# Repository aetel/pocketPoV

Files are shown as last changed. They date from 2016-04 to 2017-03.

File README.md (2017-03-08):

# pocketPoV
This little device can serve as a Persistence of View (PoV) display. Just make it swing in the air and it will display a message.

it works! pocketPoV

To program the ATtiny85 you may follow this guide:
http://highlowtech.org/?p=1706

---


pocketPoV and its surrounding materials are published under [CC BY-SA 4.0](https://creativecommons.org/licenses/by-sa/4.0/)

pocketPoV was designed by [RS](https://github.com/rsre "RS") & CBS for Telecom Electronics Association [AETEL](http://aetel.io), based at the Campus Sur of [Universidad Politécnica de Madrid](http://upm.es).

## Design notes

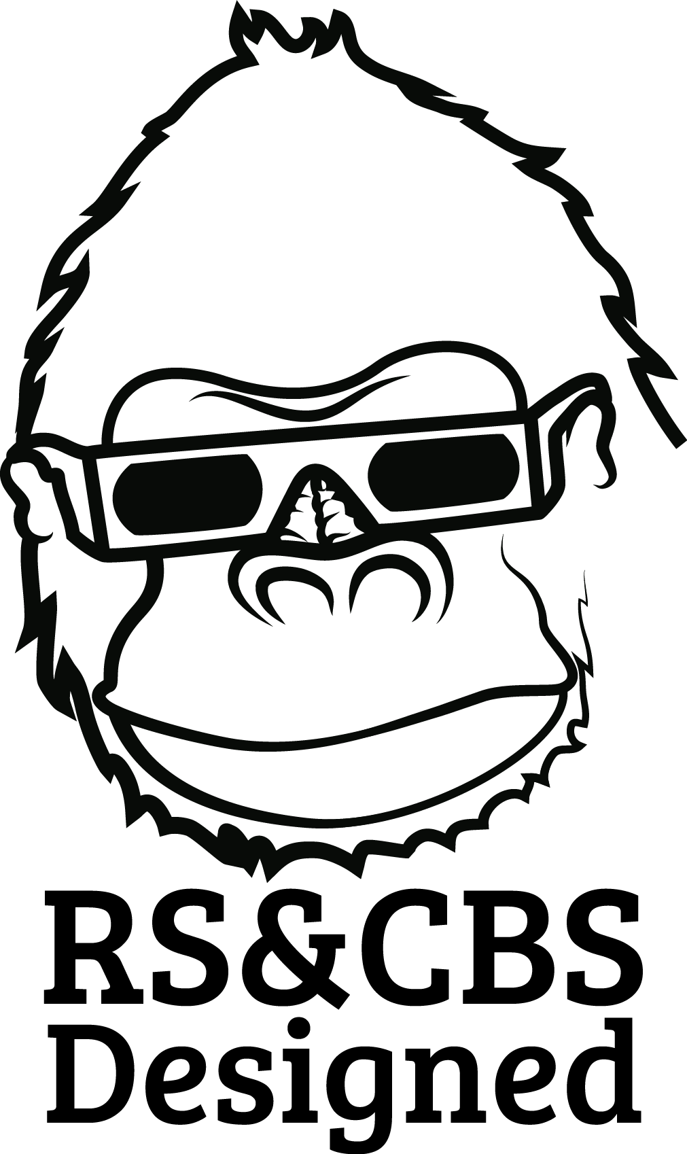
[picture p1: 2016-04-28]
images/RS&CBS.png

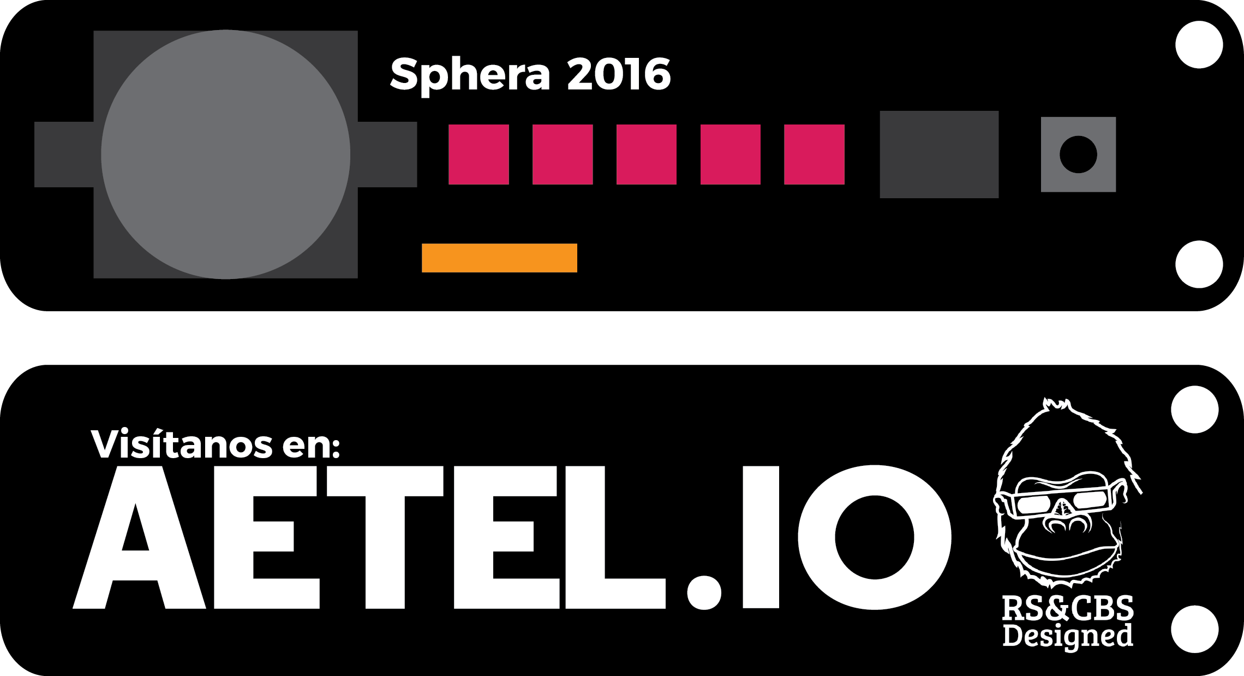
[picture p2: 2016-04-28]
images/pocketPoV.png

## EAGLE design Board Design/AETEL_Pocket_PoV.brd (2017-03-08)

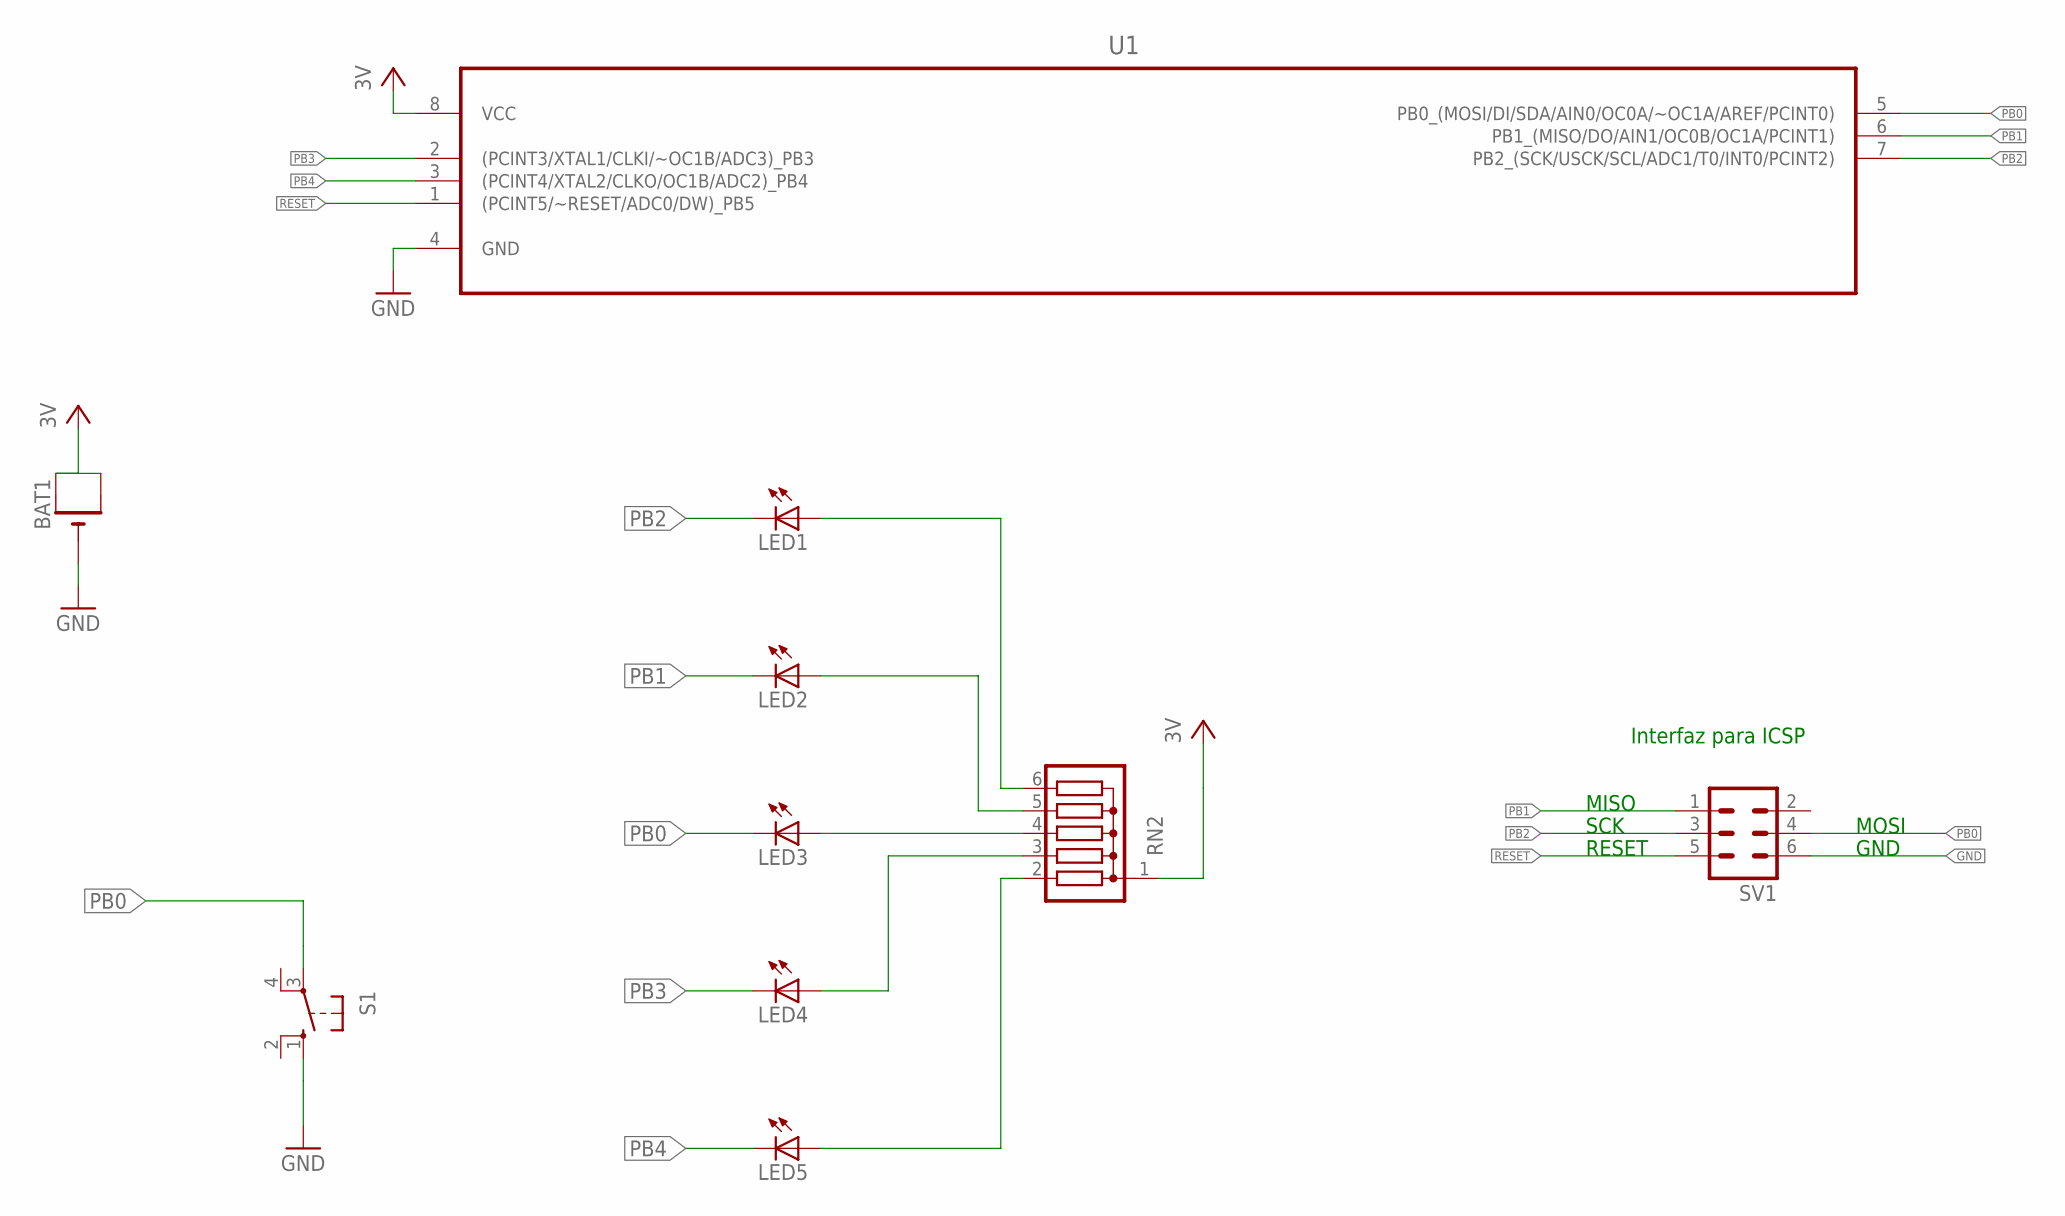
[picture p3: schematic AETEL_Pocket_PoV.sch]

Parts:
BAT1: CR2032THM; CR2032-THRU
LED1, LED2, LED3, LED4, LED5: LEDSQUARE_LED5MM; SQUARE_LED5MM
RN2: G05R; SIL6
S1: 10-XX; B3F-10XX
SV1: MA03-2
U1: ATTINY85-20PU; DIP254P762X533-8

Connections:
GND: BAT1.-, S1.1 (S), SV1.6, U1.4 (GND)
unnamed: LED3.A, RN2.4
unnamed: LED1.A, RN2.6
unnamed: LED2.A, RN2.5
unnamed: LED5.A, RN2.2
unnamed: LED4.A, RN2.3
PB0: LED3.K (C), S1.3, SV1.4, U1.5 (PB0_(MOSI/DI/SDA/AIN0/OC0A/~OC1A/AREF/P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)
PB1: LED2.K (C), SV1.1, U1.6 (PB1_(MISO/DO/AIN1/OC0B/OC1A/PCINT1))
PB2: LED1.K (C), SV1.3, U1.7 (PB2_(SCK/USCK/SCL/ADC1/T0/INT0/PCINT2))
PB3: LED4.K (C), U1.2 ((PCINT3/XTAL1/CLKI/~OC1B/ADC3)_PB3)
PB4: LED5.K (C), U1.3 ((PCINT4/XTAL2/CLKO/OC1B/ADC2)_PB4)
RESET: SV1.5, U1.1 ((PCINT5/~RESET/ADC0/DW)_PB5)
VCC: BAT1.+1 (+), BAT1.+2 (+1), RN2.1, U1.8 (VCC)

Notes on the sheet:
MOSI
MISO
SCK
RESET
GND
Interfaz para ICSP

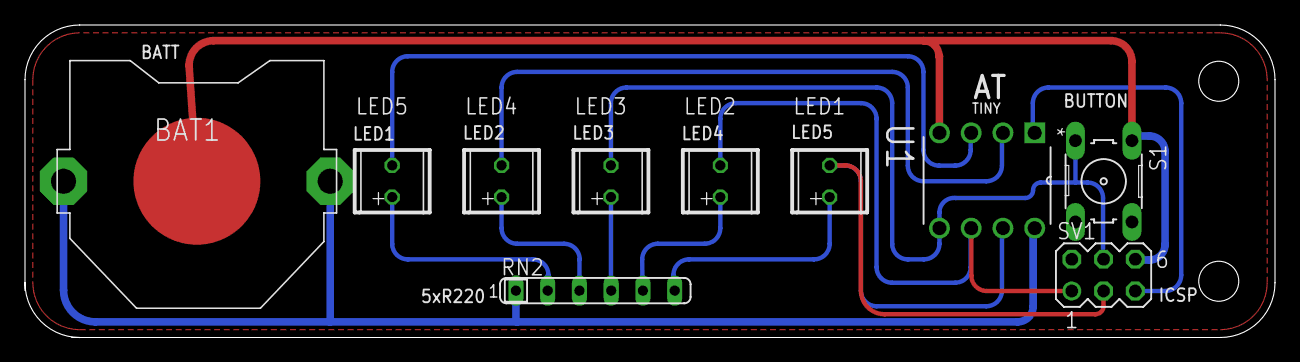
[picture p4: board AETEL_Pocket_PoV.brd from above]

Board: 2 copper layers, 100.0 x 25.0 mm, 10 parts (0 on the bottom side), 13 nets.

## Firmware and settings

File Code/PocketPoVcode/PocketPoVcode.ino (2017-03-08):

/*
 * Pocket PoV code example
 *
 * by RS
 * April 26 2016
 * remixed from the internets
 *
 * Sleep code by syntec
 * http://forum.arduino.cc/index.php?topic=271534.0
 *
 * Persistence of View display code by vishalapr
 * http://www.instructables.com/id/ATtiny8545-POV-Display/?ALLSTEPS
 */

#include <avr/sleep.h>

#ifndef cbi
#define cbi(sfr, bit) (_SFR_BYTE(sfr) &= ~_BV(bit))
#endif
#ifndef sbi
#define sbi(sfr, bit) (_SFR_BYTE(sfr) |= _BV(bit))
#endif


/*
 * Default values for turning display are:
 *
 * int delayTime = 1;
 * int charBreak = 2.1;
 *
 * for long exposure pictures (a.k.a. "lightpainting") use:
 *
 * int delayTime = 50;
 * int charBreak = 110;
 */

int delayTime = 1;
int charBreak = 2.1;

int LED1 = 4;
int LED2 = 3;
int LED3 = 0;
int LED4 = 1;
int LED5 = 2;

const int switchPin = 3;

void setup(){
  pinMode(LED1, OUTPUT);
  pinMode(LED2, OUTPUT);
  pinMode(LED3, OUTPUT);
  pinMode(LED4, OUTPUT);
  pinMode(LED5, OUTPUT);

  sbi(GIMSK,PCIE); // Turn on Pin Change interrupt
  sbi(PCMSK,PCINT0); // Which pins are affected by the interrupt
}


int a[] = {1, 6, 26, 6, 1};
int b[] = {31, 21, 21, 10, 0};
int c2[] = {14, 17, 17, 10, 0};
int d[] = {31, 17, 17, 14, 0};
int e[] = {31, 21, 21, 17, 0};
int f[] = {31, 20, 20, 16, 0};
int g[] = {14, 17, 19, 10, 0};
int h[] = {31, 4, 4, 4, 31};
int i[] = {0, 17, 31, 17, 0};
int j[] = {0, 17, 30, 16, 0};
int k[] = {31, 4, 10, 17, 0};
int l[] = {31, 1, 1, 1, 0};
int m[] = {31, 12, 3, 12, 31};
int n[] = {31, 12, 3, 31, 0};
int o[] = {14, 17, 17, 14, 0};
int p[] = {31, 20, 20, 8, 0};
int q[] = {14, 17, 19, 14, 2};
int r[] = {31, 20, 22, 9, 0};
int s[] = {8, 21, 21, 2, 0};
int t[] = {16, 16, 31, 16, 16};
int u[] = {30, 1, 1, 30, 0};
int v[] = {24, 6, 1, 6, 24};
int w[] = {28, 3, 12, 3, 28};
int x[] = {17, 10, 4, 10, 17};
int y[] = {17, 10, 4, 8, 16};
int z[] = {19, 21, 21, 25, 0};

int eos[] = {0, 1, 0, 0, 0};
int mdot[] = {0, 0, 1, 0, 0};
int excl[] = {0, 29, 0, 0, 0};
int iexcl[] = {0, 0, 0, 29, 0};
int ques[] = {8, 19, 20, 8, 0};
int spc[] = {0, 0, 0, 0, 0};

void displayLine(int line)
{
  int myline;
  myline = line;
  if (myline>=16) {digitalWrite(LED1, LOW); myline-=16;} else {digitalWrite(LED1, HIGH);}
  if (myline>=8)  {digitalWrite(LED2, LOW); myline-=8;}  else {digitalWrite(LED2, HIGH);}
  if (myline>=4)  {digitalWrite(LED3, LOW); myline-=4;}  else {digitalWrite(LED3, HIGH);}
  if (myline>=2)  {digitalWrite(LED4, LOW); myline-=2;}  else {digitalWrite(LED4, HIGH);}
  if (myline>=1)  {digitalWrite(LED5, LOW); myline-=1;}  else {digitalWrite(LED5, HIGH);}
}

void displayChar(char c)
{
  if (c == 'a'){for (int i = 0; i <5; i++){displayLine(a[i]);delay(delayTime);}displayLine(0);}
  if (c == 'b'){for (int i = 0; i <5; i++){displayLine(b[i]);delay(delayTime);}displayLine(0);}
  if (c == 'c'){for (int i = 0; i <5; i++){displayLine(c2[i]);delay(delayTime);}displayLine(0);}
  if (c == 'd'){for (int i = 0; i <5; i++){displayLine(d[i]);delay(delayTime);}displayLine(0);}
  if (c == 'e'){for (int i = 0; i <5; i++){displayLine(e[i]);delay(delayTime);}displayLine(0);}
  if (c == 'f'){for (int i = 0; i <5; i++){displayLine(f[i]);delay(delayTime);}displayLine(0);}
  if (c == 'g'){for (int i = 0; i <5; i++){displayLine(g[i]);delay(delayTime);}displayLine(0);}
  if (c == 'h'){for (int i = 0; i <5; i++){displayLine(h[i]);delay(delayTime);}displayLine(0);}
  if (c == 'i'){for (int it = 0; it <5; it++){displayLine(i[it]);delay(delayTime);}displayLine(0);}
  if (c == 'j'){for (int i = 0; i <5; i++){displayLine(j[i]);delay(delayTime);}displayLine(0);}
  if (c == 'k'){for (int i = 0; i <5; i++){displayLine(k[i]);delay(delayTime);}displayLine(0);}
  if (c == 'l'){for (int i = 0; i <5; i++){displayLine(l[i]);delay(delayTime);}displayLine(0);}
  if (c == 'm'){for (int i = 0; i <5; i++){displayLine(m[i]);delay(delayTime);}displayLine(0);}
  if (c == 'n'){for (int i = 0; i <5; i++){displayLine(n[i]);delay(delayTime);}displayLine(0);}
  if (c == 'o'){for (int i = 0; i <5; i++){displayLine(o[i]);delay(delayTime);}displayLine(0);}
  if (c == 'p'){for (int i = 0; i <5; i++){displayLine(p[i]);delay(delayTime);}displayLine(0);}
  if (c == 'q'){for (int i = 0; i <5; i++){displayLine(q[i]);delay(delayTime);}displayLine(0);}
  if (c == 'r'){for (int i = 0; i <5; i++){displayLine(r[i]);delay(delayTime);}displayLine(0);}
  if (c == 's'){for (int i = 0; i <5; i++){displayLine(s[i]);delay(delayTime);}displayLine(0);}
  if (c == 't'){for (int i = 0; i <5; i++){displayLine(t[i]);delay(delayTime);}displayLine(0);}
  if (c == 'u'){for (int i = 0; i <5; i++){displayLine(u[i]);delay(delayTime);}displayLine(0);}
  if (c == 'v'){for (int i = 0; i <5; i++){displayLine(v[i]);delay(delayTime);}displayLine(0);}
  if (c == 'w'){for (int i = 0; i <5; i++){displayLine(w[i]);delay(delayTime);}displayLine(0);}
  if (c == 'x'){for (int i = 0; i <5; i++){displayLine(x[i]);delay(delayTime);}displayLine(0);}
  if (c == 'y'){for (int i = 0; i <5; i++){displayLine(y[i]);delay(delayTime);}displayLine(0);}
  if (c == 'z'){for (int i = 0; i <5; i++){displayLine(z[i]);delay(delayTime);}displayLine(0);}
  if (c == '!'){for (int i = 0; i <5; i++){displayLine(excl[i]);delay(delayTime);}displayLine(0);}
  if (c == '¡'){for (int i = 0; i <5; i++){displayLine(iexcl[i]);delay(delayTime);}displayLine(0);}
  if (c == '?'){for (int i = 0; i <5; i++){displayLine(ques[i]);delay(delayTime);}displayLine(0);}
  if (c == '.'){for (int i = 0; i <5; i++){displayLine(eos[i]);delay(delayTime);}displayLine(0);}
  if (c == ' '){for (int i = 0; i <5; i++){displayLine(spc[i]);delay(delayTime);}displayLine(0);}
  if (c == '·'){for (int i = 0; i <5; i++){displayLine(mdot[i]);delay(delayTime);}displayLine(0);}
  delay(charBreak);
}

void displayString(char* s)
{
  for (int i = 0; i<=strlen(s); i++)
  {
    displayChar(tolower(s[i]));
  }
}

int contador;

void loop(){
  contador = 0;
  pinMode(LED4, OUTPUT);
  while(contador < (1500/delayTime)){
      displayString("teleco campus sur·");
      contador++;
  }

  pinMode(1,INPUT);
  system_sleep();
}

// From http://interface.khm.de/index.php/lab/experiments/sleep_watchdog_battery/
void system_sleep() {
  cbi(ADCSRA,ADEN); // Switch Analog to Digital converter OFF
  set_sleep_mode(SLEEP_MODE_PWR_DOWN); // Set sleep mode
  sleep_mode(); // System sleeps here
  sbi(ADCSRA,ADEN);  // Switch Analog to Digital converter ON
}

ISR(PCINT0_vect) {
}

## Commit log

2016-04-28 Added BoM, images and code
    Added BoM.
    Added board image.
    Added RS&CBS colab logo.
    Added first version of code.
    [BoM_pocketPov.csv]
2017-03-08 Added board design, working picture and license
    [AETEL_Pocket_PoV.brd, AETEL_Pocket_PoV.sch, BoM_pocketPov.csv]

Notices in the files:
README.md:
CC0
